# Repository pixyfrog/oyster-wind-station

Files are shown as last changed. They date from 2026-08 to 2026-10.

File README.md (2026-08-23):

# oyster-wind-station
Lora-based wind monitoring for kitesurfing community at Oyster Island, Kampot, Cambodia.

## Architecture
- **Transmitter (Oyster Island):** Raspberry Pi Pico (RP2040) + RFM95W LoRa + anemometer
- **Receiver (Villa Vedici):** Orange Pi 3 LTS + RFM95W LoRa + web dashboard
- **Link:** 10 km LoRa, 868 MHz, custom packet protocol

## Hardware
| Component | Spec | Status |
|---|---|---|
| Pico RP2040 ×2 | USB-C boards, bare-metal Rust | Ordered |
| RFM95W 868 MHz | SX1276, spring antenna | Ordered |
| Anemometer | NPN pulse output, 0-30 m/s | Ordered |
| Orange Pi 3 LTS | Receiver, Armbian 26.5.1 | Ready |
| 18650 Li-ion | Protected, 3500 mAh | Ordered |

## Software
- Transmitter: Rust embedded (`embassy-rs`), deep sleep between readings
- Receiver: Rust (`spidev`, `axum`), web dashboard at `http://<ip>:3000`
- Packet format: 8 bytes — `node_id | wind_speed | battery | sequence | crc`

## Status
- [x] Receiver hardware ready (Orange Pi 3 LTS, SPI enabled)
- [x] Rust toolchain installed
- [ ] LoRa driver implementation
- [ ] Web dashboard
- [ ] Transmitter firmware
- [ ] Field test (10 km link)

## License
MIT

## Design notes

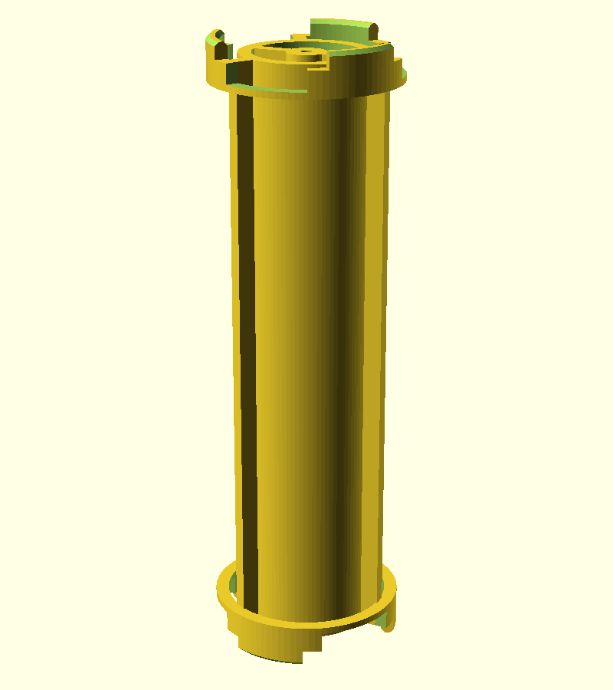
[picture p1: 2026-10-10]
oyster-chassis/renders/counterpoise.png

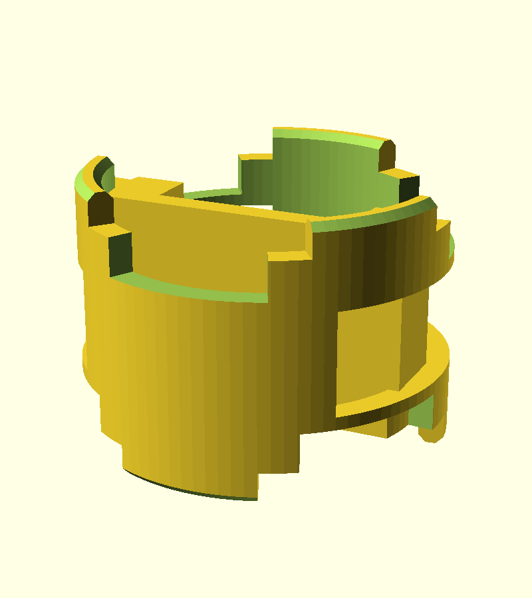
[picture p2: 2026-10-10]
oyster-chassis/renders/radio.png

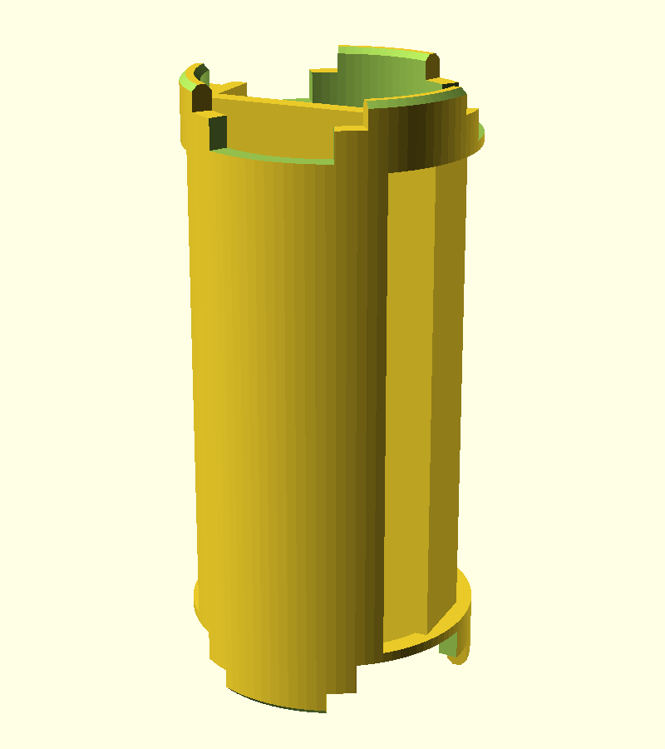
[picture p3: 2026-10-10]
oyster-chassis/renders/pico.png

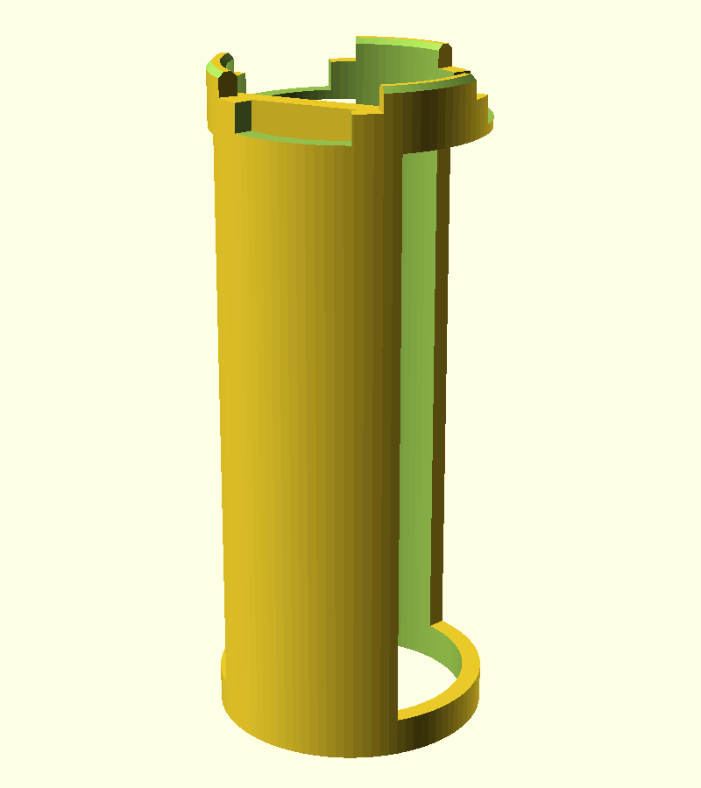
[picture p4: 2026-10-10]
oyster-chassis/renders/battery.png

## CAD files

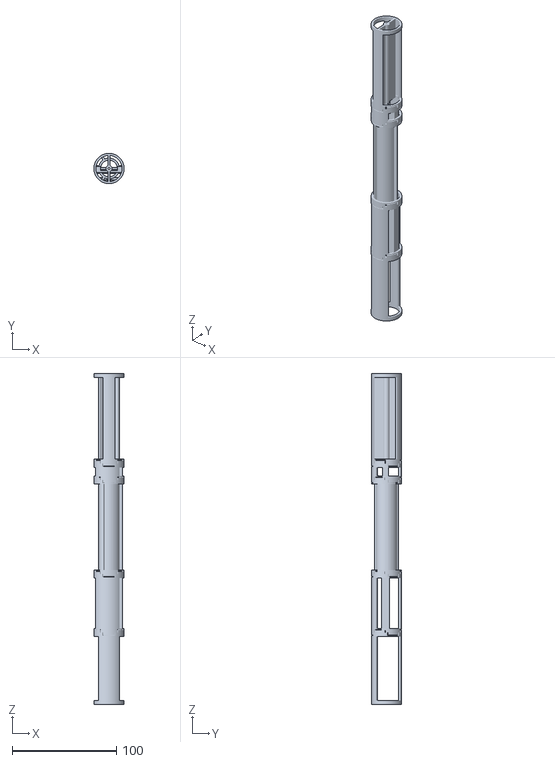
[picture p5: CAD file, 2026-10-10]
oyster-chassis/renders/assembled.stl
29.0 x 29.0 x 317.0

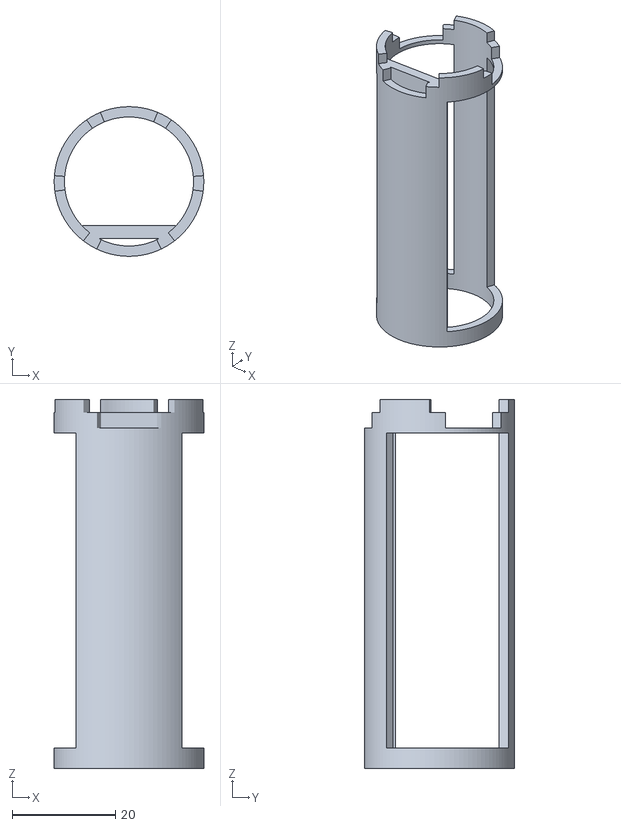
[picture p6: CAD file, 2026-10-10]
oyster-chassis/renders/battery.stl
29.0 x 29.0 x 71.5

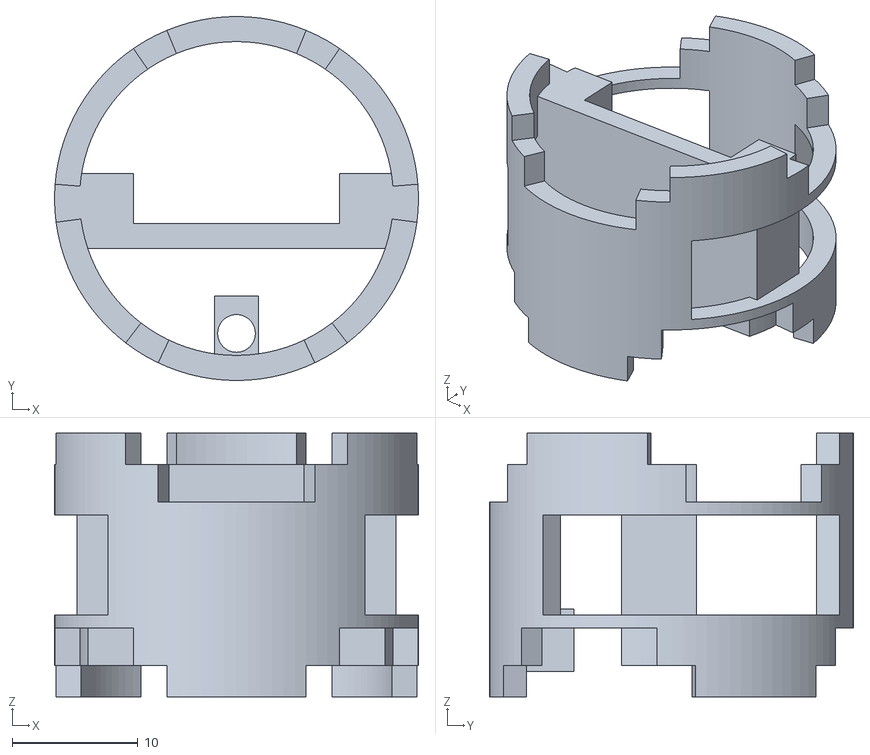
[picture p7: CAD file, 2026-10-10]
oyster-chassis/renders/radio.stl
29.0 x 29.0 x 21.0

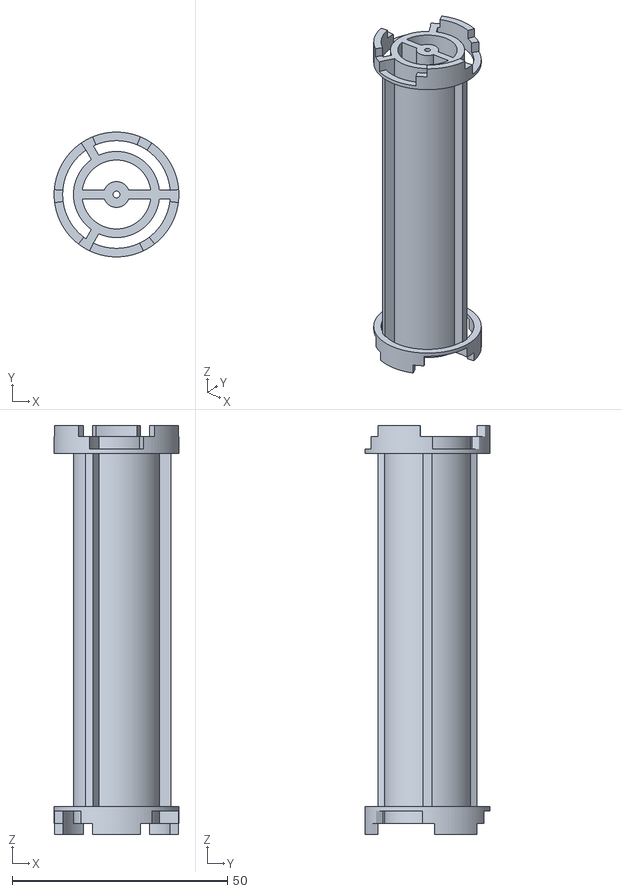
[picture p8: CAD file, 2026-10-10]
oyster-chassis/renders/counterpoise.stl
29.0 x 29.0 x 95.0

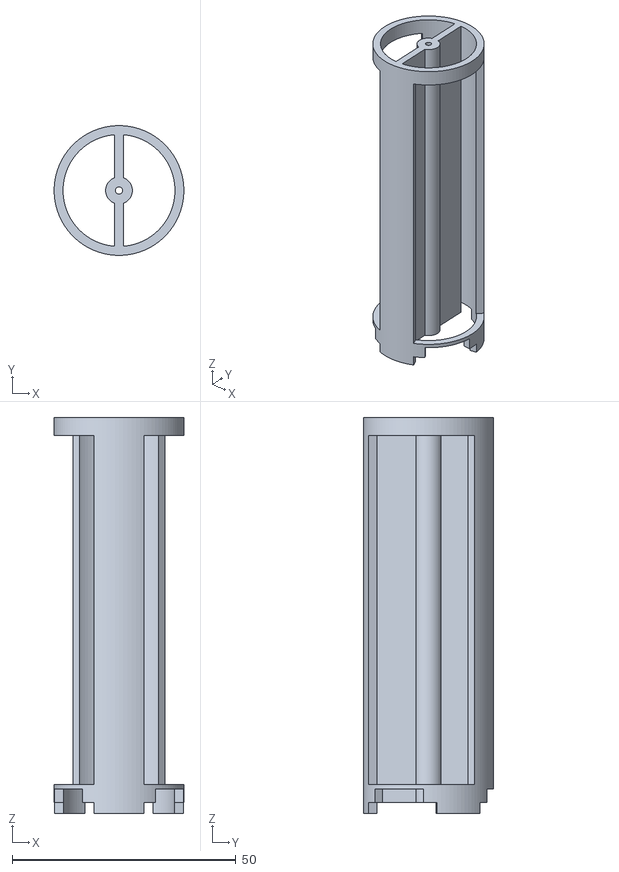
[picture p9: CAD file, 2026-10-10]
oyster-chassis/renders/antenna.stl
29.0 x 29.0 x 88.5

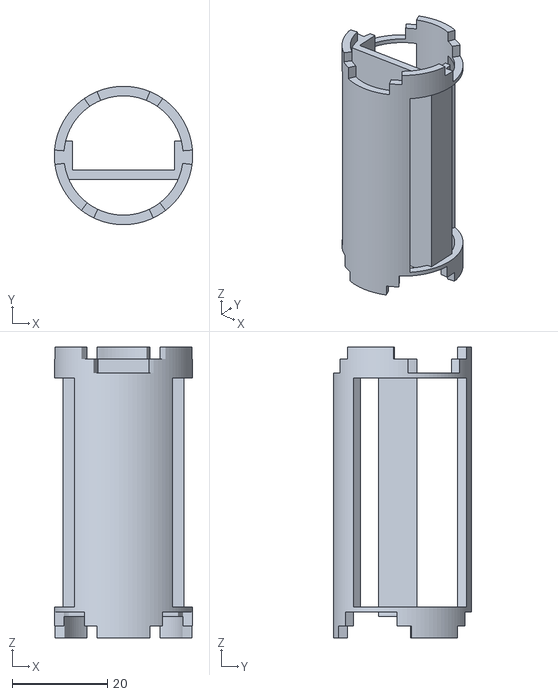
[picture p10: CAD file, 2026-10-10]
oyster-chassis/renders/pico.stl
29.0 x 29.0 x 61.0

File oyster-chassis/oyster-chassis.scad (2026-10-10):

// oyster-chassis.scad
// Skeletal, modular chassis for the Oyster island wind-station emitter tube.
//
// Five independent parts stack bottom-to-top inside the PVC bore (the PVC tube
// is NOT modelled). Each part is a small skeleton: two transverse ribs (hoops)
// joined by partial outer-shell arcs, plus one station-specific feature. The
// arcs give real FDM surface instead of thin rods. The parts are printed
// separately and glued into a chain; only the counterpoise carrier has a full
// shell, which receives the brass/copper tube.
//
//   openscad -D part=0 -o /tmp/all.stl          oyster-chassis.scad  // assembled
//   openscad -D part=1 -o /tmp/battery.stl      oyster-chassis.scad  // battery cradle
//   openscad -D part=2 -o /tmp/pico.stl         oyster-chassis.scad  // Pico bay
//   openscad -D part=3 -o /tmp/counterpoise.stl oyster-chassis.scad  // counterpoise
//   openscad -D part=4 -o /tmp/radio.stl        oyster-chassis.scad  // radio mount
//   openscad -D part=5 -o /tmp/antenna.stl      oyster-chassis.scad  // antenna guide

$fn = 96; // modest tessellation for a 4 GB machine

// Numeric part selector: integers only (-D part="name" is stripped by the shell
// and falls through to the default branch).
//   0 = assembled   1 = battery cradle   2 = Pico bay
//   3 = counterpoise carrier   4 = radio mount   5 = antenna guide
part = 0;

// ---------------------------------------------------------------------------
// Parameter block
// ---------------------------------------------------------------------------

// --- PVC tube (measured with a caliper) ---
pvc_bore = 30.5;   // measured: PVC inner diameter
pvc_od   = 34.2;   // measured: PVC outer diameter
pvc_wall = 1.85;   // measured: PVC wall thickness

// --- Printed chassis ---
chassis_od   = 29.7;   // derived: pvc_bore - 0.8 mm diametral clearance (envelope)
chassis_bore = 26.1;   // derived: reference internal envelope

// --- Printer ---
printer_z = 300;   // measured: Voron usable Z

// --- Components (measured) ---
cell_d      = 18.4;  // measured: protected 18650 diameter
cell_l      = 69.0;  // measured: protected 18650 length
pico_w      = 21.0;  // measured: Pico width  (CONFIRM with calipers before printing)
pico_l      = 51.0;  // measured: Pico length (CONFIRM with calipers before printing)
pico_bay_t  = 6.0;   // design: Pico + solder joints, no Dupont header stack
radio_w     = 16.0;  // measured: RFM95W width
radio_l     = 16.0;  // measured: RFM95W length

// --- Skeleton frame (design): two ribs (hoops) + partial shell arcs ---
collar_od   = 29.0;  // design: rib outer diameter (slides in the 30.5 bore)
collar_wall = 2.0;   // design: shell / rib wall
collar_h    = 4.0;   // design: transverse rib axial thickness
arc_a_sweep = 90.0;  // design: main partial-shell arc
arc_a_center = 90.0; // design: main arc centre (top)
arc_b_sweep = 45.0;  // design: opposite partial-shell arc
arc_b_center = 270.0;// design: opposite arc centre (bottom)
fin_t       = 2.0;   // design: vertical radial fin thickness

// --- Interlocking crenel keys at the hoop ends (design, FDM-friendly) ---
// Each part's top mates any part's bottom: 3 teeth alternate with 3 notches.
key_tooth_deg   = 45.0;   // design: tooth arc width
key_clear_deg   = 3.0;    // design: extra half-width per notch side (clearance)
key_notch_deg   = key_tooth_deg + 2 * key_clear_deg; // derived: 51 deg
key_h           = 2.5;    // design: tooth engagement depth
key_axial_clear = 0.5;    // design: axial clearance (glue room, no bottoming out)
key_notch_depth = key_h + key_axial_clear; // derived: 3.0 mm
top_teeth       = [90, 210, 330];  // top hoop teeth (one marks the 90 deg arc)
bottom_teeth    = [30, 150, 270];  // bottom hoop teeth (complementary)

// --- On-axis wire guide (design) ---
wire_guide_od   = 6.0; // design: guide tube OD
wire_guide_bore = 1.6; // design: guide bore for the wire

// --- Battery cradle feature (design) ---
// The part receives a rectangular (purchased) cradle, stuck on a flat table.
battery_table_w = 18.0;  // design: flat table width (x)
battery_table_y = -8.5;  // design: table inner face (cradle bonds here)
battery_table_t = 2.5;   // design: table thickness

// --- Pico bay feature (design) ---
pico_deck_t = 2.0;   // design: deck thickness
pico_rail_t = 1.5;   // design: side-rail thickness
pico_usb_gap = 2.0;  // design: clear gap at the bottom for the USB-C port

// --- Counterpoise carrier feature (design) ---
cp_boss_od = 20.0;   // design: boss OD, slides inside a 22 mm copper-pipe offcut (ID ~20.2)
cp_boss_id = 16.0;   // design: hollow boss bore

// --- Radio mount feature (design) ---
radio_slot_t = 4.0;  // design: board slot depth (board + components)

// --- RF / antenna (physics, do not change) ---
freq_mhz       = 868;              // frozen: LoRa centre frequency
lambda         = 300 / freq_mhz * 1000; // derived: ~345.6 mm at 868 MHz
lambda_quarter = lambda / 4;       // derived: ~86.4 mm
lambda_tenth   = lambda / 10;      // derived: ~34.6 mm
radiator_len   = 86.0;             // design: straight lambda/4 wire on axis
clearance_min  = 50.0;             // design: minimum radiator clearance

// --- Station layout, bottom (z=0) to top (measured/derived stack-up) ---
cap_h        = 20.0;                     // service cap + desiccant space
cell_z0      = cap_h;                    // 20
pico_z0      = cell_z0 + cell_l;         // 89
cp_z0        = pico_z0 + 56.0;           // 145
radio_z0     = cp_z0 + 90.0;             // 235
radiator_z0  = radio_z0 + radio_l;       // 251
radiator_z1  = radiator_z0 + radiator_len; // 337
headroom     = 20.0;                     // headroom to the sealed top
total_l      = radiator_z1 + headroom;   // 357

battery_part_l = cell_l;                 // 69  (station 1)
pico_part_l    = 56.0;                   // 56  (station 2)
cp_part_l      = 90.0;                   // 90  (station 3)
radio_part_l   = radio_l;                // 16  (station 4)
antenna_part_l = radiator_len;           // 86  (station 5)

// --- Derived clearances: radiator start to the hottest conductors below it ---
clearance_cell = radiator_z0 - (cell_z0 + cell_l); // 251 - 89  = 162
clearance_pico = radiator_z0 - cp_z0;              // 251 - 145 = 106

// ---------------------------------------------------------------------------
// Assertions: encode the physical rules. Do not loosen to make a render pass.
// ---------------------------------------------------------------------------
assert(collar_od < pvc_bore,
       "skeleton rib OD must be under the PVC bore");
assert(chassis_od < pvc_bore,
       "chassis envelope must be under the PVC bore");
assert(chassis_bore > cell_d,
       "chassis bore must clear the cell diameter");
assert(sqrt(pico_bay_t * pico_bay_t + pico_w * pico_w) < chassis_bore,
       "Pico cross-section diagonal must clear the chassis bore");
assert(pico_z0 >= cell_z0 + cell_l,
       "cell and Pico must not overlap axially (they sit in series)");
assert(clearance_cell >= clearance_min,
       "radiator clearance to the cell must be >= clearance_min");
assert(clearance_pico >= clearance_min,
       "radiator clearance to the Pico must be >= clearance_min");
assert(max(battery_part_l, max(pico_part_l, max(cp_part_l,
       max(radio_part_l, antenna_part_l)))) <= printer_z,
       "each printed part must fit under the printer height");
assert(key_h < collar_h && key_notch_depth < collar_h,
       "crenel teeth and notches must fit inside the hoop height");
assert(key_notch_deg < 120,
       "three crenel notches must fit around the hoop");

// ---------------------------------------------------------------------------
// ECHO report
// ---------------------------------------------------------------------------
echo(str("skeleton OD     = ", collar_od, " mm  (PVC bore ", pvc_bore, " mm)"));
echo(str("envelope bore   = ", chassis_bore, " mm"));
echo(str("total length    = ", total_l, " mm"));
echo(str("part lengths    = battery ", battery_part_l, ", pico ", pico_part_l,
         ", counterpoise ", cp_part_l, ", radio ", radio_part_l,
         ", antenna ", antenna_part_l));
echo(str("shell arcs      = ", arc_a_sweep, " deg top / ", arc_b_sweep, " deg bottom"));
echo(str("crenel keys     = 3 teeth, ", key_tooth_deg, " deg tooth / ", key_notch_deg,
         " deg notch, ", key_h, " mm deep, ", 2 * key_clear_deg,
         " deg + ", key_axial_clear, " mm clearance"));
echo(str("lambda/4        = ", lambda_quarter, " mm  (radiator ", radiator_len, " mm)"));
echo(str("lambda/10       = ", lambda_tenth, " mm  (min clearance ", clearance_min, " mm)"));
echo(str("radiator->cell  = ", clearance_cell, " mm"));
echo(str("radiator->Pico  = ", clearance_pico, " mm"));

// ---------------------------------------------------------------------------
// Common skeleton
// ---------------------------------------------------------------------------
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

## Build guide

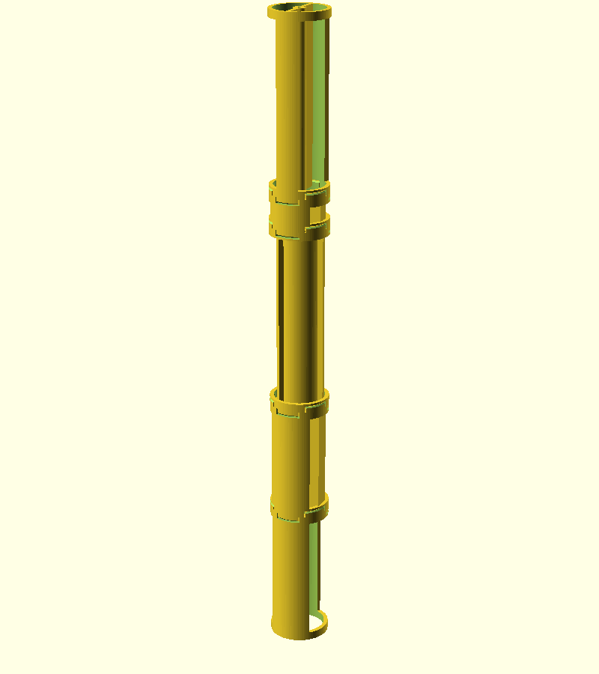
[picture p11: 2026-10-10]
oyster-chassis/renders/assembled.png

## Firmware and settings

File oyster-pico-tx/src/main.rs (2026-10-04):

#![no_std]
#![no_main]

use bsp::entry;
use panic_halt as _;
use rp_pico as bsp;

use bsp::hal::{
    clocks::{init_clocks_and_plls, Clock, ClockGate, ClockSource, ClocksManager, StoppableClock},
    fugit::RateExtU32,
    gpio::{FunctionSpi, Pins},
    pac,
    rosc::RingOscillator,
    sio::Sio,
    spi::Spi,
    watchdog::Watchdog,
    xosc::setup_xosc_blocking,
};

use embedded_hal::digital::{InputPin, OutputPin};
use embedded_hal::spi::SpiBus;
use bsp::hal::fugit::ExtU32;
use bsp::hal::timer::{Alarm, Alarm0, Timer};

use usb_device::{class_prelude::*, prelude::*};
use usbd_serial::{SerialPort, USB_CLASS_CDC};
use core::cell::RefCell;
use portable_atomic:: {AtomicBool, AtomicU32, Ordering};
use bsp::hal::gpio::{FunctionSio, Interrupt, Pin, PullUp, SioInput};
use bsp::hal::gpio::bank0::Gpio22;
use bsp::hal::pac::interrupt;
use critical_section::Mutex;

// ---------------- SX1276 regists we use ---------------
const REG_PA_DAC: u8 = 0x4D;
const PACKET_VERSION: u8 = 0x02;
// true  = bench build: USB serviced. Requires USE_PLL_CLOCK, which is what
//         makes clk_usb 48 MHz so the USB controller can be touched at all.
// false = field build: no USB setup at all. The USB controller is left in
//         reset, because with clk_usb stopped any access to its registers
//         stalls the AHB and hangs the core before the radio is driven.
const DEBUG_USB: bool = false;
// true  = full clock tree (PLL_SYS 125 MHz + PLL_USB 48 MHz).
// false = crystal only, no PLLs — they are the dominant current cost.
const USE_PLL_CLOCK: bool = false;
const SUB_SAMPLES_PER_WINDOW: u32 = 200; // — 6 for bench, 200 for real (600 s / 3 s)
const WINDOW_S: u16 = (SUB_SAMPLES_PER_WINDOW * 3) as u16; // 3s per sub_sample
const K_CM_PER_PULSE: u32 = 5; // calibrate on site
const LORA_SF: u8 = 9; // frozen range is 7 .. 9
const LORA_MODEM_CONFIG2: u8 = (LORA_SF << 4 ) | 0x04;  //SF in bit 7..4, paylod CRC on
const REG_OP_MODE: u8 = 0x01;
const REG_FRF_MSB: u8 = 0x06;
const REG_FRF_MID: u8 = 0x07;
const REG_FRF_LSB: u8 = 0x08;
const REG_PA_CONFIG: u8 = 0x09;
const REG_FIFO_ADDR_PTR: u8 = 0x0D;
const REG_FIFO_TX_BASE: u8 = 0x0E;
const REG_IRQ_FLAGS: u8 = 0x12;
const REG_MODEM_CONFIG1: u8 = 0x1D;
const REG_MODEM_CONFIG2: u8 = 0x1E;
const REG_PREAMBLE_MSB: u8 = 0x20;
const REG_PREAMBLE_LSB: u8 = 0x21;
const REG_PAYLOAD_LENGTH: u8 = 0x22;
const REG_MODEM_CONFIG3: u8 = 0x26;
const REG_SYNC_WORD: u8 = 0x39;

// RegOpMode values: 0x80 = LoRa mode + sleep, then +standby / +TX
const MODE_SLEEP: u8 = 0x80;
const MODE_STANDBY: u8 = 0x81;
const MODE_TX: u8 = 0x83;
const IRQ_TX_DONE: u8 = 0x08;

//The ISR adds to this; the mian loop drais it with swap(0).
static PULSE_COUNT: AtomicU32 = AtomicU32::new(0);

//The pin must be reachable from the ISR to clear the edge, so it lives
// in a critical-section-guarded slot rather than a local Variable.
type AnemometerPin = Pin<Gpio22, FunctionSio<SioInput>, PullUp>;
static ANEMOMETER: Mutex<RefCell<Option<AnemometerPin>>> = Mutex::new(RefCell::new(None));
static ALARM: Mutex<RefCell<Option<Alarm0>>> = Mutex::new(RefCell::new(None));
static ALARM_FIRED: AtomicBool = AtomicBool::new(false);

#[entry]
fn main() -> ! {
    let mut pac = pac::Peripherals::take().unwrap();
    let core = pac::CorePeripherals::take().unwrap();
    
    let mut watchdog = Watchdog::new(pac.WATCHDOG);
    // Bench build: full clock tree, because USB needs PLL_USB at 48 MHz.
    // Field build: crystal only, no PLLs — they are the dominant current cost
    // (PLL_SYS measured ≈ 18 mA, PLL_USB ≈ 3 mA, the crystal ≈ 0.7 mA).
    let mut clocks = if USE_PLL_CLOCK { 
        init_clocks_and_plls(
            rp_pico::XOSC_CRYSTAL_FREQ,
            pac.XOSC,
            pac.CLOCKS,
            pac.PLL_SYS,
            pac.PLL_USB,
            &mut pac.RESETS,
            &mut watchdog,
        )
        .ok()
        .unwrap()
        } else {
            // clk_ref MUST stay on the crystal: the watchdog tick, and so the TIMER's
            // 1 µs tick, derives from it. The ROSC is too imprecise to keep time.
            let xosc = setup_xosc_blocking(pac.XOSC, rp_pico::XOSC_CRYSTAL_FREQ.Hz()).unwrap();
            watchdog.enable_tick_generation((rp_pico::XOSC_CRYSTAL_FREQ / 1_000_000) as u8);
            let mut clocks = ClocksManager::new(pac.CLOCKS);
            clocks.reference_clock.configure_clock(&xosc, xosc.get_freq()).unwrap();
            // clk_ref stays on the crystal at 12 MHz for accurate timing (the watchdog
            // tick and the TIMER's 1 µs tick). clk_sys runs at a quarter of that: the
            // domains that must stay clocked through wfi (sys_io, sys_timer) burn a
            // quarter of the dynamic power, while SPI (~0.75 MHz) and the systick
            // Delay stay valid.
            clocks.system_clock.configure_clock(&xosc, (rp_pico::XOSC_CRYSTAL_FREQ / 4).Hz()).unwrap();
            clocks.peripheral_clock.configure_clock(&clocks.system_clock, clocks.system_clock.freq()).unwrap();

            // Nothing but the crystal may be left running. This mirrors pico-sdk
            // sleep_run_from_dormant_source: stop the USB and ADC clocks, power down
            // both PLLs, and stop the ring oscillator. A BOOTSEL flash can leave the
            // ROM's PLL_USB alive across the jump into the app, and a live PLL costs
            // its full current even when no clock is routed from it. The PLL power
            // register 0x2d is PD | DSMPD | POSTDIVPD | VCOPD from the SDK's pll_deinit.
            clocks.usb_clock.disable();
            clocks.adc_clock.disable();
            pac.PLL_SYS.pwr().write(|w| unsafe { w.bits(0x2d) });
            pac.PLL_USB.pwr().write(|w| unsafe { w.bits(0x2d) });
            RingOscillator::new(pac.ROSC).initialize().disable();
            clocks
        };

    // In the field build, gate every peripheral clock while the core is in wfi,
    // keeping only the two wake sources: the TIMER alarm (sys_timer) and the GP22
    // anemometer edge (sys_io + sys_pads). pico-sdk's sleep_goto_sleep_for keeps
    // only the system timer; we keep IO as well because pulses are counted in wfi.
    // wake_en (all ones) restores every clock on wake, so SPI/radio still work.
    if !DEBUG_USB {
        let mut gate = ClockGate::default();
        gate.set_sys_timer(true);
        gate.set_sys_io(true);
        gate.set_sys_pads(true);
        clocks.configure_sleep_enable(gate);
    }

    let mut delay = cortex_m::delay::Delay::new(core.SYST, clocks.system_clock.freq().to_Hz());

    let sio = Sio::new(pac.SIO);
    let pins = Pins::new(
        pac.IO_BANK0,
        pac.PADS_BANK0,
        sio.gpio_bank0,
        &mut pac.RESETS,
    );

    // ---- SPI0 to the radio (same wiring as the version-check step) ----
    let miso = pins.gpio16.into_function::<FunctionSpi>();
    let sck = pins.gpio18.into_function::<FunctionSpi>();
    let mosi = pins.gpio19.into_function::<FunctionSpi>();

    let spi = Spi::<_, _, _, 8>::new(pac.SPI0, (mosi, miso, sck));
    let mut spi = spi.init(
        &mut pac.RESETS,
        clocks.peripheral_clock.freq(),
        1_000_000u32.Hz(),
        embedded_hal::spi::MODE_0,
    );

    let mut cs = pins.gpio17.into_push_pull_output();
    let mut rst = pins.gpio20.into_push_pull_output();
    // ---- anemometer pulse input ----
    let mut anemometer = pins.gpio22.into_pull_up_input();
    anemometer.set_interrupt_enabled(Interrupt::EdgeLow, true);
    critical_section::with(|cs| ANEMOMETER.borrow(cs).replace(Some(anemometer)));
    unsafe { pac::NVIC::unmask(pac::Interrupt::IO_IRQ_BANK0) };

    let mut timer = Timer::new(pac.TIMER, &mut pac.RESETS, &clocks);
    let mut alarm = timer.alarm_0().unwrap();
    alarm.enable_interrupt();
    critical_section::with(|cs| ALARM.borrow(cs).replace(Some(alarm)));
    unsafe { pac::NVIC::unmask(pac::Interrupt::TIMER_IRQ_0) };
    // ---- USB serial (bench build only) ----
    // Skipping this entirely when DEBUG_USB = false is not just a current saving:
    // the field clock tree never starts PLL_USB, so clk_usb is stopped, and the
    // register/DPRAM writes below would stall the bus and hang the core.
    let usb_bus = if DEBUG_USB {
        Some(UsbBusAllocator::new(bsp::hal::usb::UsbBus::new(
            pac.USBCTRL_REGS,
            pac.USBCTRL_DPRAM,
            clocks.usb_clock,
            true,
            &mut pac.RESETS,
        )))
    } else {
        None
    };
    let mut serial = usb_bus.as_ref().map(SerialPort::new);
    let mut usb_dev = usb_bus.as_ref().map(|bus| {
        UsbDeviceBuilder::new(bus, UsbVidPid(0x16c0, 0x27dd))
            .device_class(USB_CLASS_CDC)
            .build()
    });

    // Reset pulse, then configure the radio for LoRa TX at 868 MHz.
    cs.set_high().unwrap();
    rst.set_low().unwrap();
    delay.delay_ms(1);
    rst.set_high().unwrap();
    delay.delay_ms(10);
    radio_init_tx(&mut spi, &mut cs);

    let mut sequence: u16 = 0;
    let mut window = Window::new();
    let mut sub_samples: u32 = 0;
    loop {
        if DEBUG_USB {
            if let (Some(dev), Some(ser)) = (usb_dev.as_mut(), serial.as_mut()) {
                dev.poll(&mut [ser]);
            }
        }

        // Measure for 3 seconds, then report.
        critical_section::with (|cs| {
            let mut slot = ALARM.borrow(cs).borrow_mut();
            if let Some(a) = slot.as_mut() {
                a.schedule(3_000_000u32.micros()).unwrap();
            }
        });
        
        while !ALARM_FIRED.load(Ordering::Relaxed) {
            if DEBUG_USB {
                if let (Some(dev), Some(ser)) = (usb_dev.as_mut(), serial.as_mut()) {
                    dev.poll(&mut [ser]);
                }
                delay.delay_ms(1);
            } else {
                cortex_m::asm::wfi();
            }
        }
        ALARM_FIRED.store(false, Ordering::Relaxed);
        let pulses = PULSE_COUNT.swap(0, Ordering::Relaxed);
        if DEBUG_USB {
            if let Some(ser) = serial.as_mut() {
                print_u16(ser, b"pulses=", pulses as u16);
            }
        }
        
        let speed = speed_cms(pulses, 3000);
        window.push(speed);
        sub_samples += 1;
        if DEBUG_USB {
            if let Some(ser) = serial.as_mut() {
                print_u16(ser, b"speed_cms=", speed as u16);
            }
        }

        if sub_samples >= SUB_SAMPLES_PER_WINDOW {
            let (avg, gust, lull) = window.finish();

            if DEBUG_USB {
                if let Some(ser) = serial.as_mut() {
                    print_u16(ser, b"avg=", avg as u16);
                    print_u16(ser, b"gust=", gust as u16);
                    print_u16(ser, b"lull=", lull as u16);
                    print_u16(ser, b"speed_cms=", speed as u16);
                }
            }

            let packet = build_packet(
                (avg / 10) as u16,
                (gust / 10) as u16,
                (lull / 10) as u16,
                3700,
                sequence,
            );
            radio_send(&mut spi, &mut cs, &mut delay, &packet);

            if DEBUG_USB {
                if let Some(ser) = serial.as_mut() {
                    print_u16(ser, b"TX seq=", sequence);
                }
            }
            sequence = sequence.wrapping_add(1);

            window = Window::new();
            sub_samples = 0;
        }
    }
}
#[pac::interrupt]
fn IO_IRQ_BANK0() {
    // Clearl the edge that fired. Miss this and the interrupt re-frires forever.
    critical_section::with(|cs| {
        let mut slot = ANEMOMETER.borrow(cs).borrow_mut();
            if let Some(pin) = slot.as_mut() {
            pin.clear_interrupt(Interrupt::EdgeLow);
        }
    });
    PULSE_COUNT.fetch_add(1, Ordering::Relaxed);
}
#[interrupt]
fn TIMER_IRQ_0() {
    critical_section::with(|cs| {
        let mut slot = ALARM.borrow(cs).borrow_mut();
        if let Some(a) = slot.as_mut() {
            a.clear_interrupt();
        }
    });
    ALARM_FIRED.store(true, Ordering::Relaxed);
}
// ---------------- radio drivers ----------------
// `impl SpiBus<u8>` = "any type that fulfils the SpiBus contract".
// You know traits as shared contracts — this just uses one as a
// parameter type so we don't have to spell out the HAL's long type name.

fn write_register(spi: &mut impl SpiBus<u8>, cs: &mut impl OutputPin, address: u8, value: u8) {
    let mut buf = [address | 0x80, value]; // MSB set = write
    cs.set_low().unwrap();
    let _ = spi.transfer_in_place(&mut buf);
    cs.set_high().unwrap();
}

fn read_register(spi: &mut impl SpiBus<u8>, cs: &mut impl OutputPin, address: u8) -> u8 {
    let mut buf = [address & 0x7F, 0x00]; // MSB clear = read
    cs.set_low().unwrap();
    let _ = spi.transfer_in_place(&mut buf);
    cs.set_high().unwrap();
    buf[1]
}
// whatch teh pulse line for 'gate_ms' millseconds and count falling edges.
 // The line stays HIGH through the pull-up; each pulse pulls it LOW; so a 
 // HIGH -> LOW change is one pulse.
fn count_pulses_for(
    pin: &mut impl InputPin,
    delay: &mut cortex_m::delay::Delay,
    gate_ms: u32,
) -> u32 {
    let mut previous = pin.is_high().unwrap();
    let mut pulses: u32 = 0;

    for _ in 0..gate_ms {
        delay.delay_ms(1);
        let now = pin.is_high().unwrap();
        if previous && !now {
            pulses += 1;
        }
        previous = now;
    }

    pulses
}
fn speed_cms(pulses: u32, window_ms: u32) -> u32 {
    let window_s = window_ms / 1000;
    if window_s == 0 {
        return 0;
    }
    (pulses * K_CM_PER_PULSE) / window_s
}
//One measurement window, hold the numbers has subsample arrives
struct Window {
    sum_cms: u32,
    sample: u32 ,
    gust_cms: Option<u32>,
    lull_cms: Option<u32>,
}

impl Window {
    fn new() -> Self {
        Window {
        sum_cms : 0,
        sample : 0,
        gust_cms : None,
        lull_cms : None,
    }
    }
    fn push(&mut self, speed_cms: u32) {
        self.sum_cms += speed_cms;
        self.sample += 1;

        if self.gust_cms.is_none() || speed_cms > self.gust_cms.unwrap() {
            self.gust_cms = Some(speed_cms);
        }
        if self.lull_cms.is_none() || speed_cms < self.lull_cms.unwrap() {
            self.lull_cms = Some(speed_cms);
        }
    } 

    // return average, gust, lull, all in cms 
    fn finish(&self) -> (u32, u32, u32) {
        (
            if self.sample == 0 {0} else {self.sum_cms/self.sample},
            self.gust_cms.unwrap_or(0),
            self.lull_cms.unwrap_or(0),
            )
    }
}

// Burst write to the FIFO: CS stays low across address byte + all data bytes.
fn write_fifo(spi: &mut impl SpiBus<u8>, cs: &mut impl OutputPin, data: &[u8]) {
    cs.set_low().unwrap();
    let _ = spi.write(&[0x80]); // register 0x00 (FIFO), write mode
    let _ = spi.write(data);
    cs.set_high().unwrap();
}

fn radio_init_tx(spi: &mut impl SpiBus<u8>, cs: &mut impl OutputPin) {
    write_register(spi, cs, REG_OP_MODE, MODE_SLEEP); // LoRa mode can only be set in sleep
    // 868 MHz: frf = 868e6 * 2^19 / 32e6 = 0xD90000 (same math as the Orange Pi)
    write_register(spi, cs, REG_FRF_MSB, 0xD9);
    write_register(spi, cs, REG_FRF_MID, 0x00);
    write_register(spi, cs, REG_FRF_LSB, 0x00);

    write_register(spi, cs, REG_MODEM_CONFIG1, 0x72); // BW 125 kHz, CR 4/5, explicit header
    write_register(spi, cs, REG_MODEM_CONFIG2, LORA_MODEM_CONFIG2); // SF9, payload CRC on
    write_register(spi, cs, REG_MODEM_CONFIG3, 0x04); // AGC auto
    write_register(spi, cs, REG_PREAMBLE_MSB, 0x00);
    write_register(spi, cs, REG_PREAMBLE_LSB, 0x08);  // preamble = 8 symbols
    write_register(spi, cs, REG_SYNC_WORD, 0x12);
    write_register(spi, cs, REG_FIFO_TX_BASE, 0x00);
    write_register(spi, cs, REG_PA_DAC, 0x87); // enable teh +20 dBfm PAG_BOOST mode
    write_register(spi, cs, REG_PA_CONFIG, 0xFF);  // PA_BOOST, ceiling 7, trim 15
    // Rest in SLEEP, not STANDBY: between init and the first radio_send (one whole
    // measurement window) the module would otherwise idle in standby at ~1.5 mA.
    write_register(spi, cs, REG_OP_MODE, MODE_SLEEP);
}

fn radio_send(
    spi: &mut impl SpiBus<u8>,
    cs: &mut impl OutputPin,
    delay: &mut cortex_m::delay::Delay,
    payload: &[u8],
) {
    write_register(spi, cs, REG_OP_MODE, MODE_STANDBY);
    write_register(spi, cs, REG_FIFO_ADDR_PTR, 0x00); // write at TX base address
    write_register(spi, cs, REG_PAYLOAD_LENGTH, payload.len() as u8);
    write_fifo(spi, cs, payload);
    write_register(spi, cs, REG_OP_MODE, MODE_TX);  
    for _ in 0..500 {
        if read_register(spi, cs, REG_IRQ_FLAGS) & IRQ_TX_DONE != 0 {
            break;
        }
        delay.delay_ms(1);
    }

    write_register(spi, cs, REG_IRQ_FLAGS, 0xFF);     // clear all IRQ flags
    write_register(spi, cs, REG_OP_MODE, MODE_SLEEP); // radio naps between packets
}

// ---------------- packet (same format as packet.rs) ----------------

fn crc8_sum(data: &[u8]) -> u8 {
    let mut crc: u8 = 0;
    for b in data {
        crc = crc.wrapping_add(*b);
    }
    crc
}
fn build_packet(
    avg_01: u16,
    gust_01: u16,
    lull_01: u16,
    battery_mv: u16,
    sequence: u16,
    ) -> [u8; 18]{
    let mut p = [0u8; 18];
    p[0] = 0xAA;            // magic
    p[1] = PACKET_VERSION;  // 0x02
    p[2] = 1;               // node id
    p[3] = 0;               // flags (unused for now)
    p[4] = (avg_01 >> 8) as u8; // wind_avg, big-endian
    p[5] = (avg_01 & 0xFF) as u8;
    p[6] = (gust_01 >> 8) as u8;
    p[7] = (gust_01 & 0xFF) as u8;
    p[8] = (lull_01 >> 8) as u8;
    p[9] = (lull_01 & 0xFF) as u8;
    p[10] = (battery_mv >> 8) as u8;
    p[11] = (battery_mv & 0xFF) as u8;
    p[12] = (sequence >> 8) as u8;
    p[13] = (sequence & 0xFF) as u8;
    p[14] = (WINDOW_S >> 8) as u8;
    p[15] = (WINDOW_S & 0xFF) as u8;
    p[16] = SUB_SAMPLES_PER_WINDOW as u8;
    p[17] = crc8_sum(&p[0..17]);
    p
}


// ---------------- serial printing helpers ----------------

fn write_all(serial: &mut SerialPort<'_, bsp::hal::usb::UsbBus>, mut data: &[u8]) {
    while !data.is_empty() {
        match serial.write(data) {
            Ok(n) if n > 0 => data = &data[n..],
            _ => break,
        }
    }
}

// Decimal print without any formatting library: peel digits off the end
// (v % 10) into a small array, then send the filled slice.
fn print_u16(serial: &mut SerialPort<'_, bsp::hal::usb::UsbBus>, label: &[u8], mut v: u16) {
    let mut digits = [b'0'; 5];
    let mut i = 5;
    if v == 0 {
        i = 4;
    }
    while v > 0 {
        i -= 1;
        digits[i] = b'0' + (v % 10) as u8;
        v /= 10;
    }
    write_all(serial, label);
    write_all(serial, &digits[i..]);
    write_all(serial, b"\r\n");
}

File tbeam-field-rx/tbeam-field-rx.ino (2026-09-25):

// ============================================================
// T-Beam V1.2 — Oyster field receiver
// Receives 9-byte WindPacket from the Pico, shows RSSI/SNR on
// the OLED, logs every packet + GPS position to flash (CSV).
//
// DUMP MODE: hold the user button (GPIO38) while pressing RST.
// The log prints over USB serial instead of receiving.
// ============================================================

#include <Wire.h>
#include <SPI.h>
#include <RadioLib.h>
#include <XPowersLib.h>
#include <TinyGPS++.h>
#include <Adafruit_GFX.h>
#include <Adafruit_SSD1306.h>
#include <LittleFS.h>

// ---- T-Beam V1.2 pins ----
#define LORA_CS   18
#define LORA_IRQ  26   // DIO0
#define LORA_RST  23
#define LORA_DIO1 33
#define LORA_SCK   5
#define LORA_MISO 19
#define LORA_MOSI 27
#define I2C_SDA   21
#define I2C_SCL   22
#define GPS_RX    34
#define GPS_TX    12
#define BUTTON    38   // user button; if dump mode never triggers, try 0

XPowersAXP2101 PMU;
Adafruit_SSD1306 display(128, 64, &Wire, -1);
TinyGPSPlus gps;
HardwareSerial gpsSerial(1);
SX1276 radio = new Module(LORA_CS, LORA_IRQ, LORA_RST, LORA_DIO1);

volatile bool rxFlag = false;
void setRxFlag() { rxFlag = true; }   // called by interrupt on DIO0

File logFile;

uint16_t lastSeq = 0;
float lastWind = 0, lastBatt = 0, lastRssi = 0, lastSnr = 0;
uint8_t  lastVersion = 0;              // 1 or 2: which format this packet used
float    lastGust = 0, lastLull = 0;   // v2 only - meaningless until lastVersion == 2
uint16_t lastWindowS = 0;              // v2 only: reporting window, in seconds
unsigned long lastRxMs = 0;
uint32_t rxCount = 0;

uint8_t crc8_sum(const uint8_t* d, size_t n) {
  uint8_t c = 0;
  for (size_t i = 0; i < n; i++) c = (uint8_t)(c + d[i]);
  return c;
}

// v1 (9 B) and v2 (18 B) BOTH start with 0xAA, so dispatch on LENGTH,
// never on the version byte - byte 1 is not trustworthy until the CRC
// has passed. Returns true and fills the last* variables only if good.
bool parsePacket(const uint8_t* b, size_t len) {
  size_t crcAt;
  if (len == 9)       crcAt = 8;    // v1: sum of bytes 0..7,  crc at index 8
  else if (len == 18) crcAt = 17;   // v2: sum of bytes 0..16, crc at index 17
  else return false;                // unknown length -> drop it (fail closed)

  if (b[0] != 0xAA) return false;
  if (crc8_sum(b, crcAt) != b[crcAt]) return false;

  if (len == 9) {                                 // ---- v1 ----
    lastSeq     = (b[6] << 8) | b[7];
    lastWind    = ((b[2] << 8) | b[3]) / 10.0;    // the mean
    lastBatt    = (b[4] << 8) | b[5];
    lastVersion = 1;
  } else {                                        // ---- v2 ----
    lastSeq     = (b[12] << 8) | b[13];
    lastWind    = ((b[4] << 8) | b[5]) / 10.0;    // avg - same 0.1 m/s scale
    lastGust    = ((b[6] << 8) | b[7]) / 10.0;
    lastLull    = ((b[8] << 8) | b[9]) / 10.0;
    lastBatt    = (b[10] << 8) | b[11];
    lastWindowS = (b[14] << 8) | b[15];
    lastVersion = 2;
  }
  return true;
}

void setup() {
  Serial.begin(115200);
  delay(500);
  pinMode(BUTTON, INPUT_PULLUP);

  Wire.begin(I2C_SDA, I2C_SCL);

  // Power rails: ALDO2 feeds the SX1276, ALDO3 feeds the GPS
  PMU.begin(Wire, AXP2101_SLAVE_ADDRESS, I2C_SDA, I2C_SCL);
  PMU.setALDO2Voltage(3300); PMU.enableALDO2();
  PMU.setALDO3Voltage(3300); PMU.enableALDO3();

  display.begin(SSD1306_SWITCHCAPVCC, 0x3C);
  display.clearDisplay();
  display.setTextSize(1);
  display.setTextColor(SSD1306_WHITE);
  display.setCursor(0, 0);
  display.println("OYSTER FIELD RX");
  display.display();

  LittleFS.begin(true);

  // Dump mode: button held at boot -> print log over serial, then stop
  if (digitalRead(BUTTON) == LOW) {
    File f = LittleFS.open("/log.csv", "r");
    if (f) {
      Serial.println("---- BEGIN LOG ----");
      while (f.available()) Serial.write(f.read());
      Serial.println("---- END LOG ----");
      f.close();
    } else {
      Serial.println("no log file");
    }
    display.println("DUMP MODE");
    display.println("see serial monitor");
    display.display();
    while (true) delay(1000);
  }

  bool newFile = !LittleFS.exists("/log.csv");
  logFile = LittleFS.open("/log.csv", "a");
  if (newFile) logFile.println("utc,lat,lon,sats,seq,wind_ms,batt_mv,rssi,snr");

  gpsSerial.begin(9600, SERIAL_8N1, GPS_RX, GPS_TX);

  SPI.begin(LORA_SCK, LORA_MISO, LORA_MOSI, LORA_CS);
  int state = radio.begin(868.0, 125.0, 9, 5, 0x12, 10, 8, 0);
  if (state != RADIOLIB_ERR_NONE) {
    display.print("radio fail ");
    display.println(state);
    display.display();
    while (true) delay(1000);
  }
  radio.setDio0Action(setRxFlag, RISING);
  radio.startReceive();
}

void loop() {
  // hold the user button 3 s -> power off (battery stays in)
  static unsigned long btnDown = 0;
  if (digitalRead(BUTTON) == LOW) {
    if (btnDown == 0) btnDown = millis();
    if (millis() - btnDown > 3000) {
      display.clearDisplay();
      display.setCursor(0, 0);
      display.println("powering off...");
      display.display();
      logFile.flush();
      logFile.close();      // seal the log properly
      delay(500);
      PMU.shutdown();       // AXP2101 cuts all rails
    }
  } else {
  btnDown = 0;
  }
  // feed the GPS parser constantly
  while (gpsSerial.available()) gps.encode(gpsSerial.read());
  if (rxFlag) {
    rxFlag = false;

    uint8_t buf[64];
    size_t len = radio.getPacketLength();
    if (len > sizeof(buf)) len = sizeof(buf);
    int state = radio.readData(buf, len);

      if (state == RADIOLIB_ERR_NONE && parsePacket(buf, len)) {


      lastRssi = radio.getRSSI();
      lastSnr  = radio.getSNR();
      lastRxMs = millis();
      rxCount++;

      char ts[12] = "no-fix";
      if (gps.time.isValid()) {
        snprintf(ts, sizeof(ts), "%02d:%02d:%02d",
                 gps.time.hour(), gps.time.minute(), gps.time.second());
      }
      double lat = gps.location.isValid() ? gps.location.lat() : 0.0;
      double lon = gps.location.isValid() ? gps.location.lng() : 0.0;

      String line = String(ts) + "," + String(lat, 5) + "," + String(lon, 5) + "," +
                    String(gps.satellites.value()) + "," + String(lastSeq) + "," +
                    String(lastWind, 1) + "," + String((int)lastBatt) + "," +
                    String(lastRssi, 1) + "," + String(lastSnr, 1);
      logFile.println(line);
      logFile.flush();          // survive sudden power-off
      Serial.println(line);     // USB backup / live monitoring
    }
    radio.startReceive();       // re-arm for the next packet
  }

  updateDisplay();
}
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

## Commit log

2026-07-22 Initial receiver: SPI test and web server scaffold
2026-07-22 Add RFM95W module, packet struct, error handling, and web dashboard
    [main.rs, rfm95w.rs]
2026-07-25 README: transmitter is RP2040, not Pico 2
    Updated the README to correct component names and specifications.
2026-08-23 Real SPI communication with RFM95W: version register reads 0x12
2026-09-05 Add Pico RP2040 LoRa transmitter firmware
2026-09-07 Fix sketch path to match Arduino folder convention
    [tbeam-field-rx.ino]
2026-09-07 Show T-beam battery voltage on OLED
2026-09-22 Pico: add anemometer pin GP21 as pulled-up input
2026-09-22 Pico: reassign anemom to gpio 22
2026-09-23 Pico: count anemometer pulses over a timed gate
2026-09-23 pico: pulse to wind ms conversion
2026-09-23 pico: update packet with speed
2026-09-23 Pico: aggregate sub-samples into avg/gust/lull with Window
2026-09-24 Pico: report and reset the window every 600 s
    [main.rs]
2026-09-24 Pico: 18-byte packet v2 with avg/gust/lull, window_s and n_sub
2026-09-25 receiver: web dashboard fix
    [main.rs]
2026-09-25 Pico: debug 16bytes packet encoding
2026-09-25 Pico: aplied PA_BOOST 20db and SF9
2026-09-26 Pico: count anemometer pulses with a GPIO interrupt
2026-09-27 Pico: create alarm driven gate
2026-09-27 Pico: Implement Sleep between sample
2026-10-01 Pico: create build flag selecting the clock tree
2026-10-02 Pico: small ; debug
2026-10-02 Pico: field build transmits — keep USB out of the no-PLL clock tree
    The field build never reached radio_send. Two faults on the no-USB path:
    the USB stack (UsbBus/SerialPort/UsbDeviceBuilder) was constructed
    unconditionally while clk_usb was stopped by the no-PLL clock tree, and
    touching USBCTRL/DPRAM then stalls the AHB; and the "pulses=" print was
    not behind DEBUG_USB. USB is now built only when DEBUG_USB is true, all
    prints are gated, and the clock choice moves to its own USE_PLL_CLOCK
    flag so clock and USB can be flashed independently.
    Bench-verified: field build (DEBUG_USB=false, USE_PLL_CLOCK=false) is
    decoded by the T-Beam at RSSI -45/-47 dBm, SNR 10-13 dB, seq 0 then 1.
    [main.rs]
2026-10-02 Pico: field sleep — de-init PLLs/ROSC and gate peripherals in wfi
    A BOOTSEL flash leaves the ROM's clock/PLL context alive across the jump
    into the app, so the field build sat at 9.2 mA. Mirroring pico-sdk
    sleep_run_from_dormant_source — stop clk_usb/clk_adc, power down both
    PLLs (PWR=0x2d), disable the ROSC once clk_ref is on the crystal —
    dropped it to 7.3 mA. Setting sleep_en so wfi keeps only sys_timer,
    sys_io and sys_pads (the alarm and the GP22 pulse edge) dropped it again
    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
2026-10-02 Pico: field sleep — rest radio in SLEEP, run clk_sys at 6 MHz
    radio_init_tx now leaves the SX1276 in MODE_SLEEP, so it no longer idles
    in standby for the first measurement window. clk_sys moves to XOSC/2
    (6 MHz) while clk_ref stays on the crystal at 12 MHz for timing: the
    domains that must stay clocked through wfi (sys_io, sys_timer) burn half
    the dynamic power, and SPI (1 MHz) and the 1 ms delay stay valid.
    Bench: steady 6.15 -> 5.92 mA; T-Beam still decodes at the 18 s cadence.
    [main.rs]
2026-10-02 Pico: field sleep — clk_sys to XOSC/4 (3 MHz)
    Diminishing return: 6.15 -> 5.92 -> 5.85 mA as clk_sys goes 12 -> 6 ->
    3 MHz. clk_ref stays at 12 MHz for timing; SPI drops to ~0.75 MHz, still
    far inside the SX1276 limit. T-Beam decodes at 3 MHz.
2026-10-04 pico: field aggregation constants — 200 sub-samples (600 s window)
2026-10-04 docs: add AGENTS.md — production build is cargo build --release
2026-10-10 chassis: parameter block, assertions and ECHO report (no geometry)
    [oyster-chassis.scad]
2026-10-10 chassis: cell_cradle — snap-in thin C-sleeve with bottom stop ring
    [oyster-chassis.scad]
2026-10-10 chassis: pico_bay — axial USB-down tray with side rails and wire reliefs
    [oyster-chassis.scad]
2026-10-10 chassis: sleeve_boss — hollow counterpoise carrier with retention rings
    [oyster-chassis.scad]
2026-10-10 chassis: radio_mount — vertical RFM95W U-cradle, ANT up/GND down, tie-down loop
    [oyster-chassis.scad]
2026-10-10 chassis: antenna_guide — skeletal 3-strut cage with hub collars for the lambda/4 wire
    [oyster-chassis.scad]
2026-10-10 chassis: joining shell, radial ribs and removable service cap
    [oyster-chassis.scad]
2026-10-10 chassis: segment split at z=89 with press-fit spigot/socket lap joint
    [oyster-chassis.scad]
2026-10-10 chassis: move scad into oyster-chassis/ and add final renders (PNG + STL)
    [cradle.stl, oyster-chassis.scad, section_a.stl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]
2026-10-10 chassis: redesign as modular skeletal stations (2 ribs + axial members), refresh renders
    [antenna.stl, assembled.stl, battery.stl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]
2026-10-10 chassis: replace rods with partial shell arcs (90/45) and add on-axis wire guides
    [antenna.stl, assembled.stl, battery.stl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]
2026-10-10 chassis: battery flat bonding table (drop trough/straps); 90-deg arc below Pico table
    [antenna.stl, assembled.stl, battery.stl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]
2026-10-10 chassis: radio_mount rebuilt as Pico-style table bay (90-deg arc below), 16 mm kept
    [antenna.stl, assembled.stl, battery.stl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]
2026-10-10 chassis: interlocking 3-crenel keys on hoop ends (clearance-tuned for FDM), refresh renders
    [antenna.stl, assembled.stl, battery.stl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]
2026-10-10 chassis: remove tooth-tip bevel (flat tips for first-layer surface); refresh STLs
    [antenna.stl, assembled.stl, battery.stl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]
2026-10-11 Pico: fix sleep bin imports so default cargo build/run works
    [sleep.rs]
2026-10-11 Pico: default-run so cargo run flashes tx; drop debug scaffolding and dead code
2026-10-11 calibrate the wind-speed measurement
2026-10-12 chassis: enlarge guide bore, offset guides, grow battery/pico/radio bays
2026-10-13 chassis: drop 45-degree shell arc from battery cradle (V3)
2026-10-16 pico: bench sub-sample cadence (6 per 3s window)
2026-10-16 pico: compute packet flags byte (sensor_ok, batt_low, window_truncated)
2026-10-16 pico: send each packet twice ~1s apart inside the window close
2026-10-16 pico: read real battery voltage from VSYS divider on ADC3
2026-10-16 pico: field build reports battery as not measured (ADC needs PLL); bench keeps bounded read
2026-10-16 pico: make the redundant-send gap a bounded wfi wait in the field build
2026-10-16 Revert "pico: make the redundant-send gap a bounded wfi wait in the field build"
    This reverts commit 18e6c124eea8af6af22b74a1893846ab5ac300fa.
2026-11-06 pico: field build + range-test cadence (SUB_SAMPLES_PER_WINDOW 200 -> 2)
